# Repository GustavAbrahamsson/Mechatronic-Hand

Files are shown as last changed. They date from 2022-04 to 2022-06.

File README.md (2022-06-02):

# Mechatronic Hand

Mechatronic hand for bachelors thesis at Chalmers University of Technology.

### Members:

 - Gustav Abrahamsson 
 - Adam Anderson
 - Nicholas Granlund
 - Johannes Lundahl
 - Anna Molnö
 - Johan Wellander

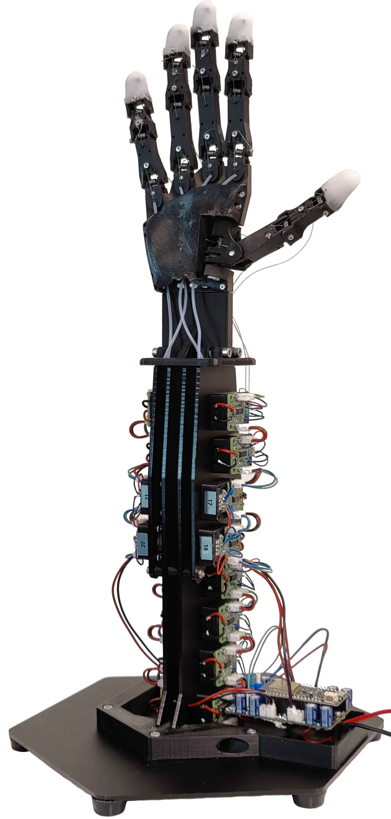
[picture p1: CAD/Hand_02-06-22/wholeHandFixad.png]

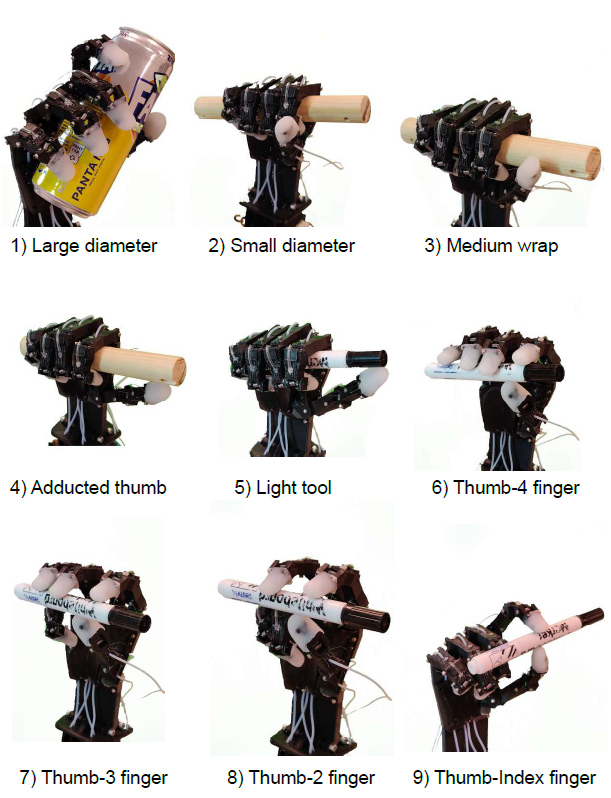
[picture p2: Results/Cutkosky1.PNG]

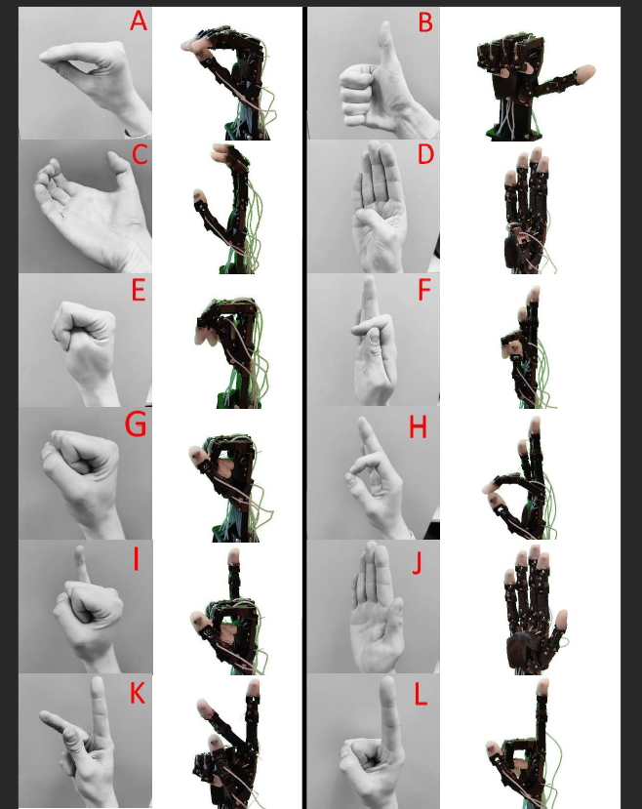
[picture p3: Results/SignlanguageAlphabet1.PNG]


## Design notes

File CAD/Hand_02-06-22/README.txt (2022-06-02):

Assembling this hand takes some time, but if you want to make it move it's going to take an eternity.
Soldering together 16 PCBs, crimping all of the jumper wires, calibrating setpoints from the potentiometers,
attaching wires and tightnening them etc is very time intensive and very troublesome. Feel free to try,
but we would recommend sticking with assembling the hand itself and maybe the lower arm WITHOUT the motors,
electronics and cables.

For the joints: Mostly M2 screws but with 4 M3 screws near the knuckles as well as an M4 and an M6 in the
base of the thumb.

The torsion springs were made by hand.

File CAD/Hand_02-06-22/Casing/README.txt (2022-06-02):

Not used in the final design, only tested. Silicone fingertips are so much better, but the other parts made it look more similar to a real hand.

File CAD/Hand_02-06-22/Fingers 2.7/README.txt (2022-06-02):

The Distal phalanges are similar for all four fingers, but there is either a straight one or a "T"-shaped one (used for silicone molded fingertip).

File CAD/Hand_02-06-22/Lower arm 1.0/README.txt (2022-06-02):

STL files to 3D print:
4 x 7mmDistans
2 x 8.8mmDistans
1 x Connector
1 x 3DprintedBase

DXF files to lasercut/CNC:
Everything is 3 mm thick matte black acrylic
2 x mainPlate1.0
2 x sidePlate1.0
1 x bottomPlate1.0

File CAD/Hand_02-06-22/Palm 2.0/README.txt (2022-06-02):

Palm2.0 was SLS printed, and FrontPalm1.2 was printed in an FDM printer with TPU plastic (not crucial though).
Make sure that the channels in the palm don't get filled up with support material, and if you SLS print; the excess filament might be difficult to remove.

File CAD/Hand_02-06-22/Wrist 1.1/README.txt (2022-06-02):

Not included in the final design due to the DC-motors only having 43% of the advertised torque..
It's therefore not finalized and cannot be mounted to the lower arm, only to the hand.

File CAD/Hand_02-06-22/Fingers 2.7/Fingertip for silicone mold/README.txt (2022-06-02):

Use this fingertip if you are going to cast silicone fingertips with the included molds

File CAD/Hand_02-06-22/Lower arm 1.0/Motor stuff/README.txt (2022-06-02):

16 of these are needed if you want to build it with motors.

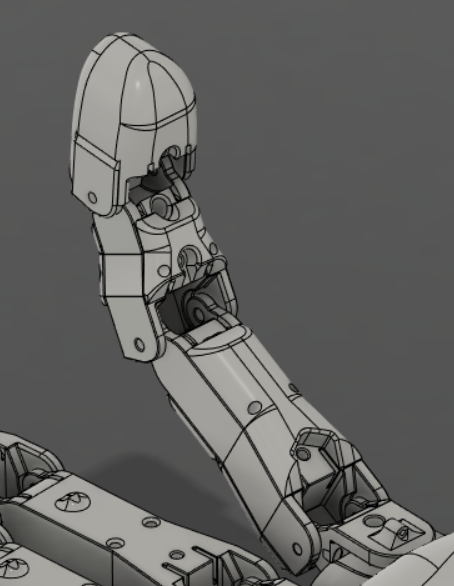
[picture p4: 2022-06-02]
CAD/Hand_02-06-22/Casing/CasingPicture.PNG

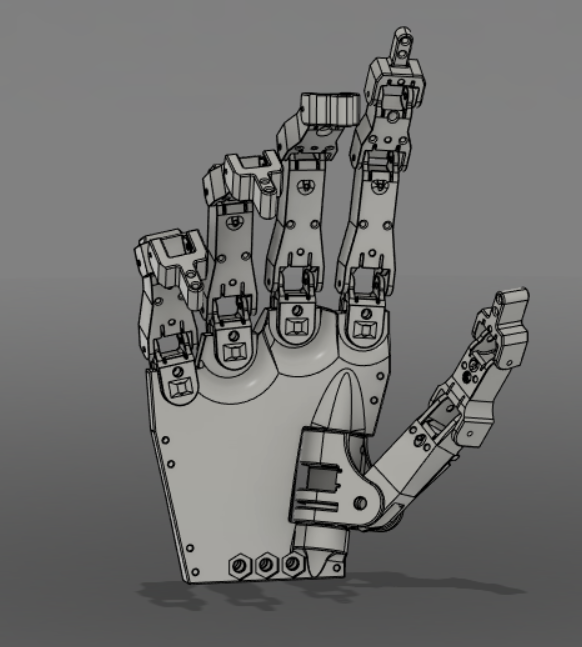
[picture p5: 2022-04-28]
CAD/Hand_02-06-22/Picture(withStraightFingertips).PNG

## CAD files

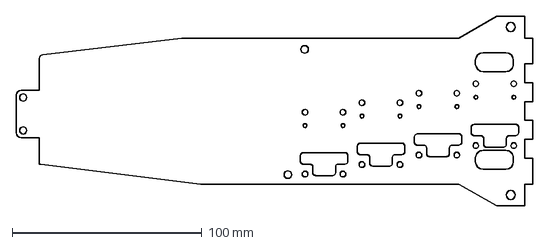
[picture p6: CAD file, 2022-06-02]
CAD/Hand_02-06-22/Lower arm 1.0/mainPlate1.0.dxf
272.1 x 99.9 mm

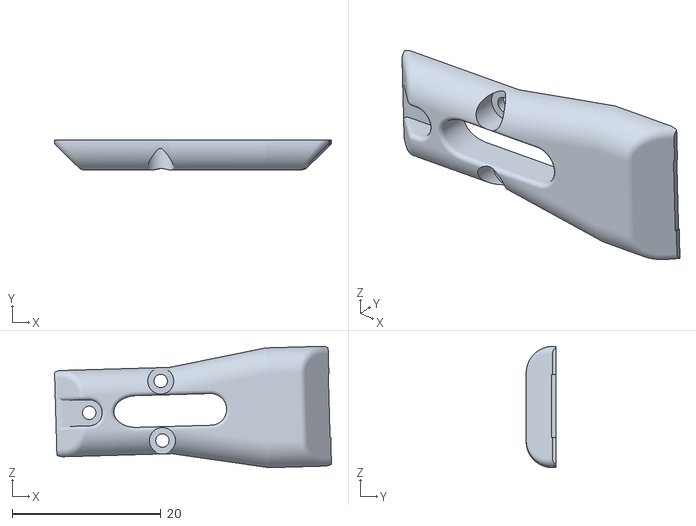
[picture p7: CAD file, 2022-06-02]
CAD/Hand_02-06-22/Casing/IndexProxBack.stl
37.2 x 4.02 x 16.3

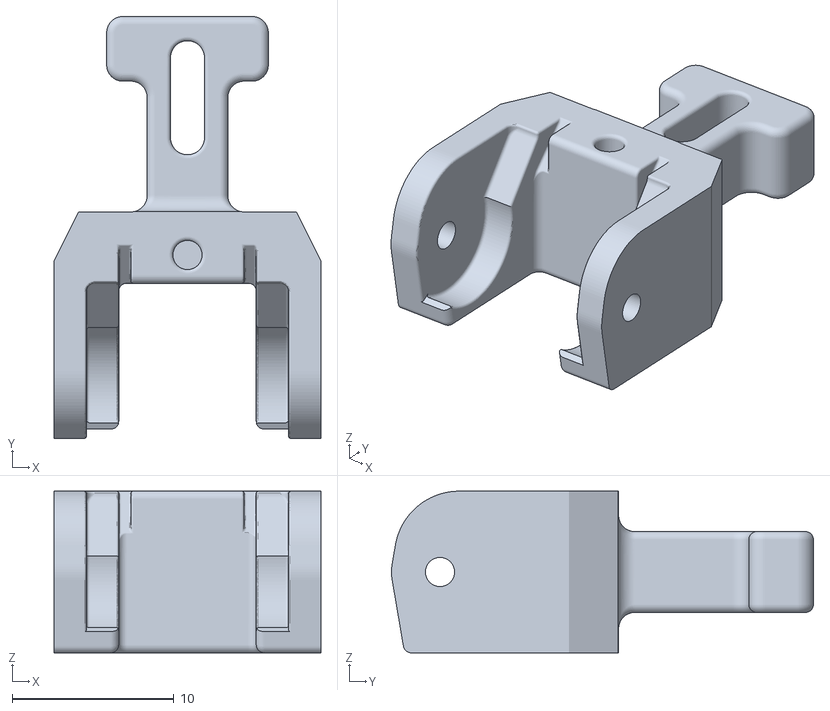
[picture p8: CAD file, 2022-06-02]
CAD/Hand_02-06-22/Fingers 2.7/Fingertip for silicone mold/Fingertip for silicone mold.stl
16.5 x 26.1 x 10.0

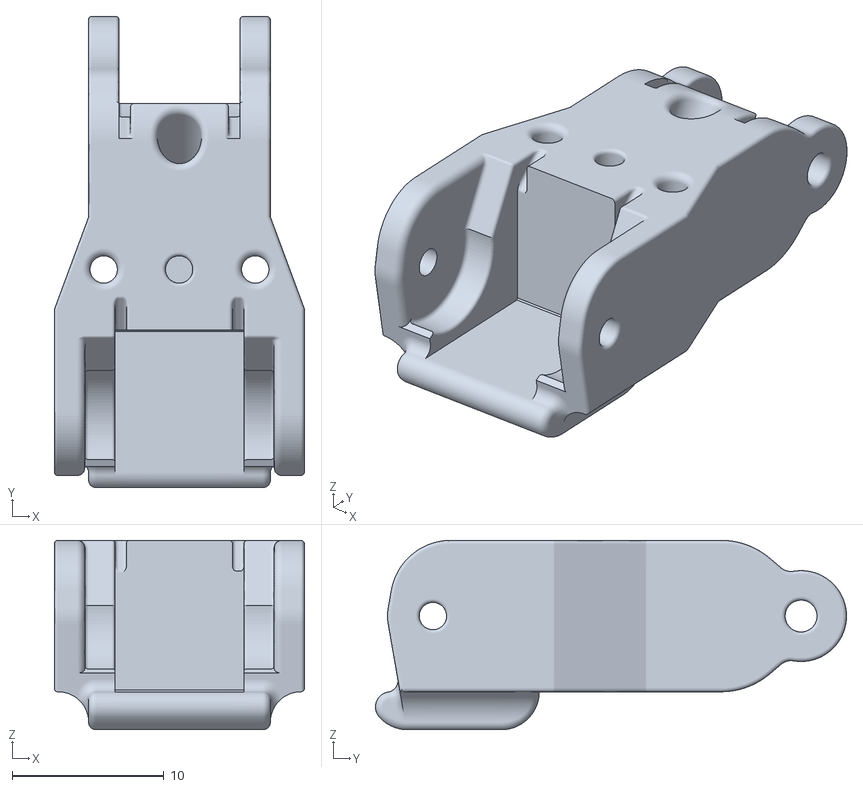
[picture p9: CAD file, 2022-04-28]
CAD/Hand_02-06-22/Fingers 2.7/Index/Intermediate phalanx.stl
16.5 x 31.1 x 12.5

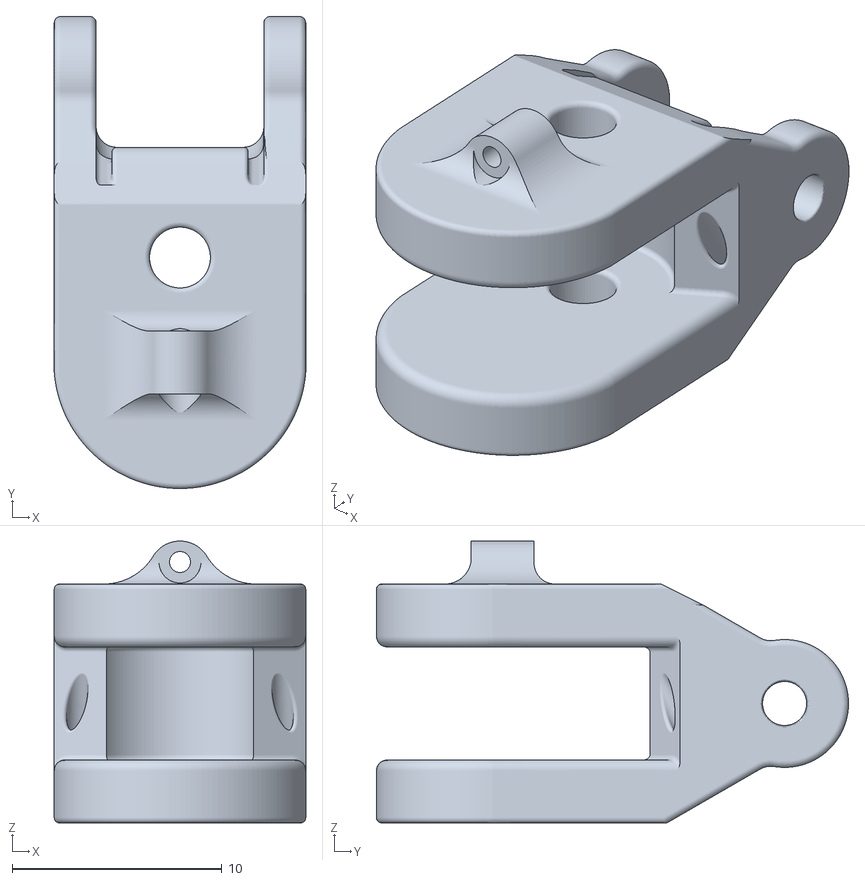
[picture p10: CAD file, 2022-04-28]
CAD/Hand_02-06-22/Fingers 2.7/Little/MCP_base.stl
12.0 x 22.5 x 13.4

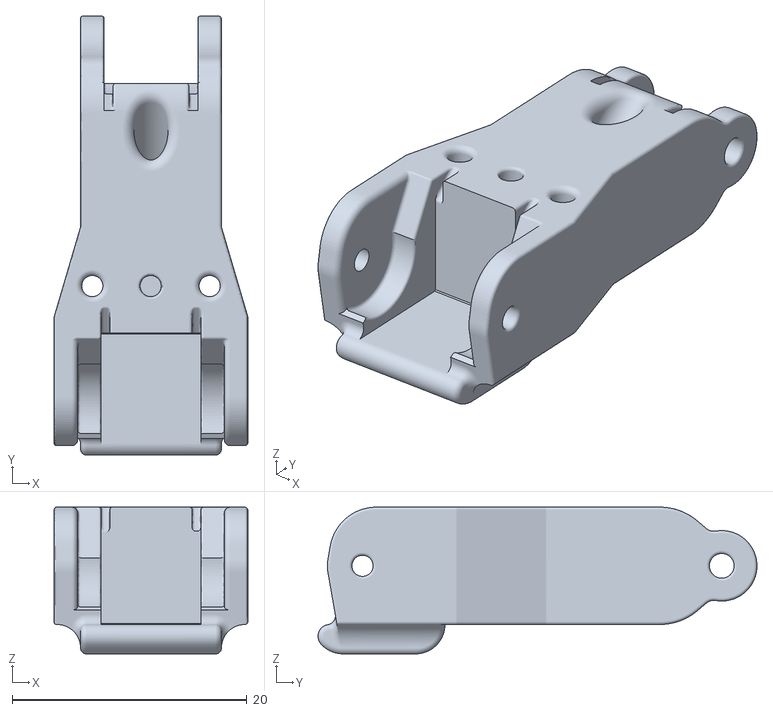
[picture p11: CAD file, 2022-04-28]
CAD/Hand_02-06-22/Fingers 2.7/Middle/Intermediate phalanx.stl
16.5 x 37.4 x 12.5

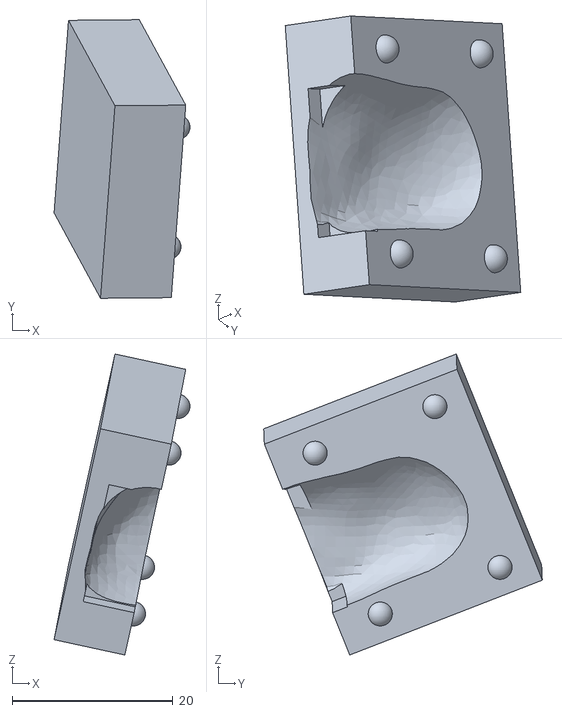
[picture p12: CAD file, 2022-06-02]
CAD/Hand_02-06-22/Fingers 2.7/Molds for finger tips/Finger mold/bottom.stl
16.9 x 34.6 x 37.4

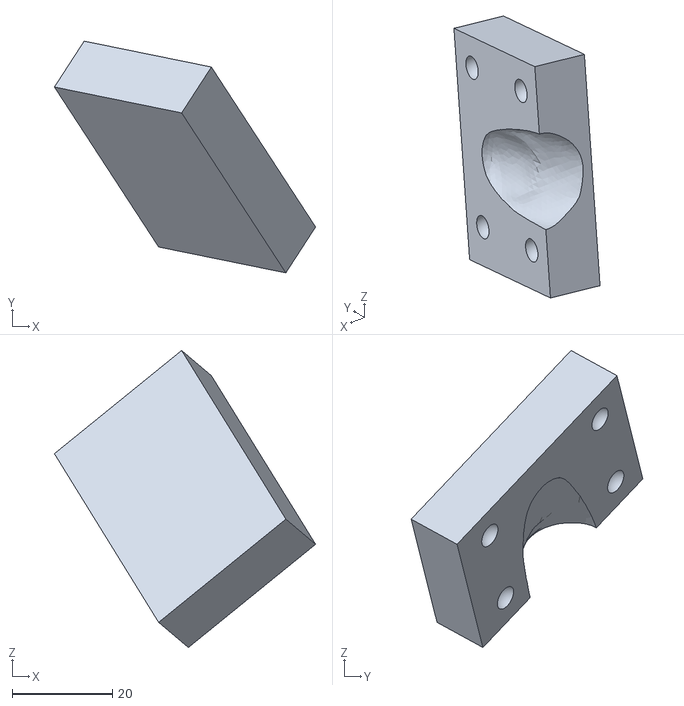
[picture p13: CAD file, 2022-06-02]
CAD/Hand_02-06-22/Fingers 2.7/Molds for finger tips/Thumb mold/Top.stl
52.1 x 46.2 x 59.2

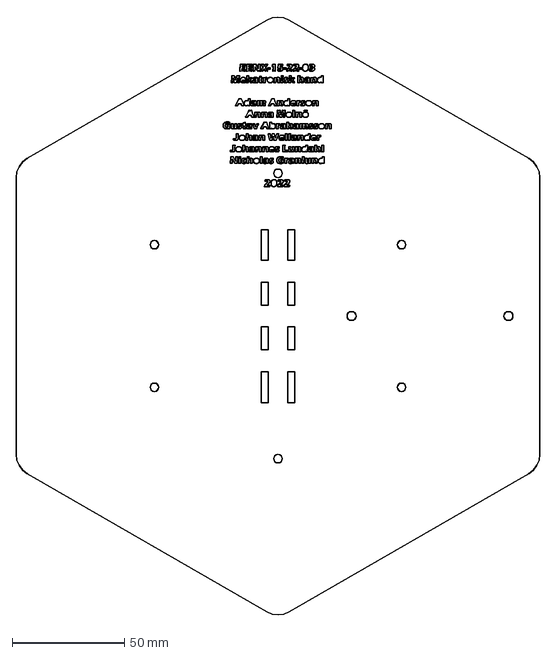
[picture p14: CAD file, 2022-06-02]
CAD/Hand_02-06-22/Lower arm 1.0/bottomPlate1.0.dxf
233.8 x 267.8 mm

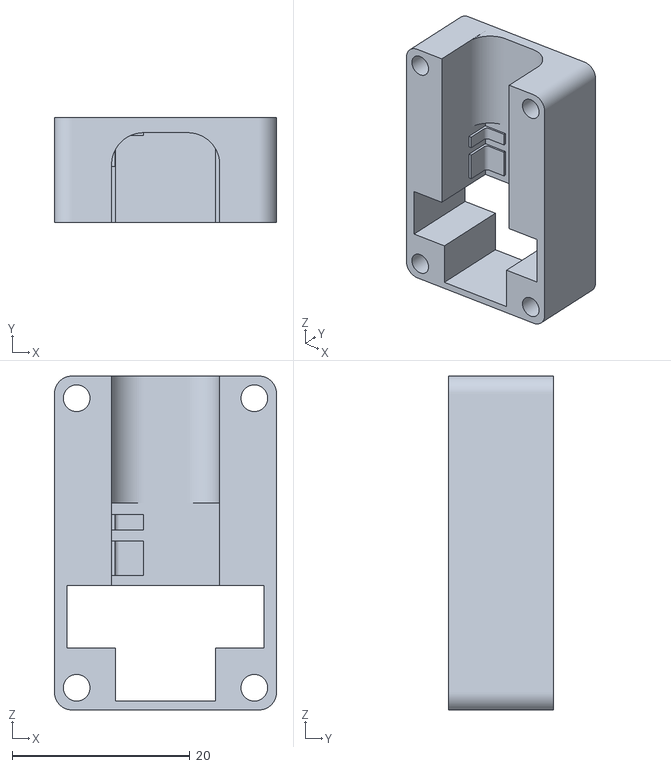
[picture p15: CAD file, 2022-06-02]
CAD/Hand_02-06-22/Lower arm 1.0/Motor stuff/Servoholder4.stl
25.0 x 11.8 x 37.6

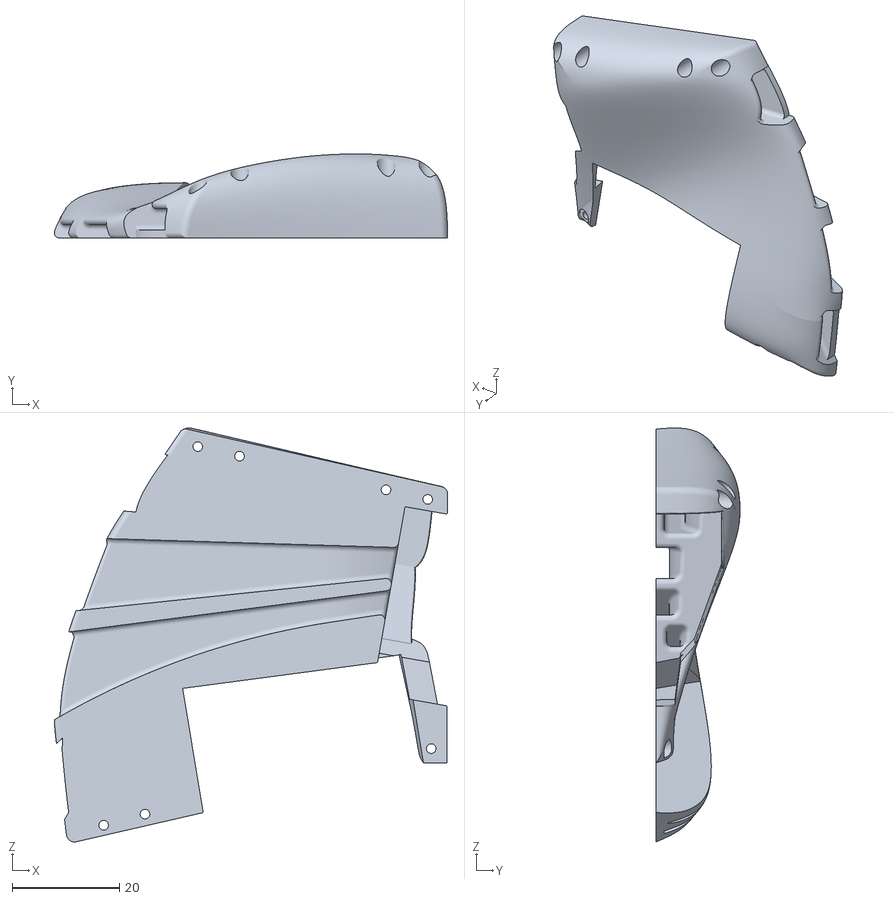
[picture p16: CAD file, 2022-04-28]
CAD/Hand_02-06-22/Palm 2.0/FrontPalm1.2.stl
73.5 x 15.7 x 77.4

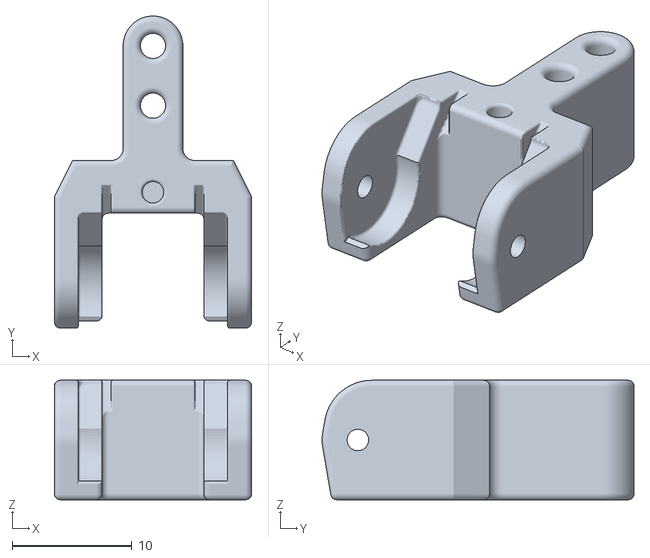
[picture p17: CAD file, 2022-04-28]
CAD/Hand_02-06-22/Thumb 1.5/distalthumbtest v1.stl
16.5 x 26.1 x 10.0

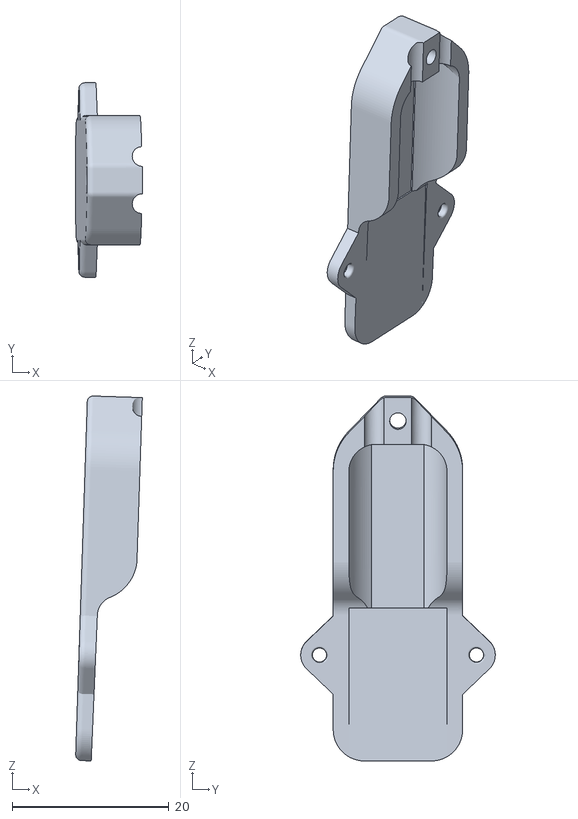
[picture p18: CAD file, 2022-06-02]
CAD/Hand_02-06-22/Wrist 1.1/MotorLid.stl
8.50 x 24.8 x 46.5

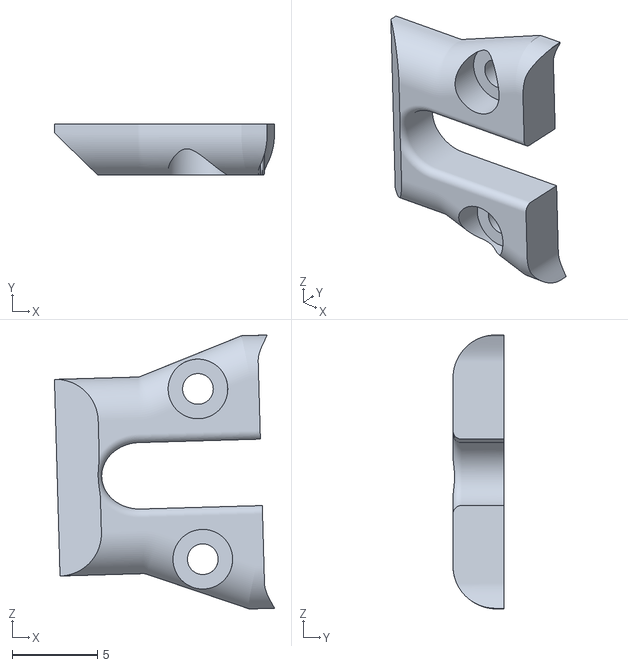
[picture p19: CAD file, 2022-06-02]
CAD/Hand_02-06-22/Casing/IndexInterBack.stl
12.9 x 3.01 x 16.1

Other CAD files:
CAD/Hand_02-06-22/Fingers 2.7/Index/Proximal phalanx.stl
CAD/Hand_02-06-22/Fingers 2.7/Little/Distal phalanx.stl
CAD/Hand_02-06-22/Fingers 2.7/Middle/Distal phalanx.stl
CAD/Hand_02-06-22/Casing/IndexInterFront.stl
CAD/Hand_02-06-22/Casing/IndexProxFront.stl
CAD/Hand_02-06-22/Casing/Short distal.stl
CAD/Hand_02-06-22/Casing/SoftDistal.stl
CAD/Hand_02-06-22/Fingers 2.7/Index/Distal phalanx.stl
CAD/Hand_02-06-22/Fingers 2.7/Little/Intermediate phalanx.stl
CAD/Hand_02-06-22/Fingers 2.7/Little/Proximal phalanx.stl
CAD/Hand_02-06-22/Fingers 2.7/Middle/MCP_base.stl
CAD/Hand_02-06-22/Fingers 2.7/Middle/Proximal phalanx.stl
CAD/Hand_02-06-22/Fingers 2.7/Molds for finger tips/Finger mold/top.stl
CAD/Hand_02-06-22/Fingers 2.7/Molds for finger tips/Thumb mold/Bottom.stl
CAD/Hand_02-06-22/Fingers 2.7/Ring/Distal phalanx.stl
CAD/Hand_02-06-22/Fingers 2.7/Ring/Intermediate phalanx.stl
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

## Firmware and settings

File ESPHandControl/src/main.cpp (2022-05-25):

#include <Arduino.h>
#include <WiFi.h>
#include <esp_now.h>
#include "MotorControl.h"
#include "Wire.h"
#include "angles.h"
#include "Math.h"

#define POT_IN 15
#define BTN 4

int letter = 0;
bool pressed = false;

uint32_t currentTime = 0;
uint32_t lastTime = 0;

uint32_t phaseShift = 3000;
float waveTime = 500.0;

uint8_t indexAngle  = 0;
uint8_t middleAngle = 0;
uint8_t ringAngle   = 0;
uint8_t littleAngle = 0;

uint8_t sequenceIndex = 0;

uint8_t CMCangle = 0;

int mode = 1;

enum joint{
  IP_TMB,
  MCP_TMB,
  CMC_TMB,
  ABD_TMB,
  MCP_1,
  PIP_1,
  ABD_1,
  MCP_2,
  PIP_2,
  ABD_2,
  MCP_3,
  PIP_3,
  ABD_3,
  MCP_4,
  PIP_4,
  ABD_4,
};

//List of 16 motor objects
MotorControl motors[16] = {
  MotorControl(11, 280, 50, 0, 90), // Thumb IP
  MotorControl(10, 440, 125, 0, 90), // Thumb MCP
  MotorControl(9, 445, 120, 0, 90), // Thumb rotation
  MotorControl(8, 448, 240, 0, 45), // Thumb abduction

  MotorControl(16, 260, 530, 0, 90), //MCP 1
  MotorControl(12, 130, 390, 0, 90), // PIP 1
  MotorControl(18, 540, 615, -15, 15), // ABD 1

  MotorControl(17, 240, 540, 0, 90 ), //MCP 2
  MotorControl(13, 330, 580, 0, 90), // PIP 2
  MotorControl(19, 530, 620, -15, 15), // ABD 2

  MotorControl(20, 710, 400, 0, 90), //MCP 3
  MotorControl(14, 275, 500, 0, 90), // PIP 3
  MotorControl(22, 520, 440, -15, 15), // ABD 3

  MotorControl(21, 710, 450, 0, 90), //MCP 4
  MotorControl(15, 270, 490, 0, 90), // PIP 4
  MotorControl(23, 670, 570, -15, 15), // ABD 4
};


//uint8_t broadcastAdress[] = {0x94,0xB9,0x7E,0xE4,0x84,0x34}; //MAC-adress till den svarta
//uint8_t broadcastAdress[] = {0x7C,0x9E,0xBD,0x60,0xD1,0x8C}; //MAC till den med kondensatorn
//uint8_t broadcastAdress[] = {0X7C,0X9E,0XBD,0X61,0X58,0XF4}; //MAC till den med vit tejp
uint8_t broadcastAdress[] = {0x94,0xB9,0x7E,0xE5,0x31,0xD8}; //MAC till Hand lolin

typedef struct struct_message{
  int sendID;
  float thumbIP;
  float thumbMCP;
  float finger1PIP;
  float finger1MCP;
  float finger2PIP;
  float finger2MCP;
  float finger3PIP;
  float finger3MCP;
  float finger4PIP;
  float finger4MCP;
  float thumbOpp;
  float finger1Pot;
  float finger2Po;
  float finger3Po;
  float finger4Po;
  float pot1;
  float pot2;
  float pot3;
  float pot4;
  float opposition;
 }struct_message;


struct_message msg_to_send;
struct_message recv_data;
float joint_positions[8];

// // Callback when data is sent, triggered when something is sent
void OnDataSent(const uint8_t *mac_addr, esp_now_send_status_t status) {
    Serial.print("\r\nLast Packet Send Status:\t");
    Serial.println(status == ESP_NOW_SEND_SUCCESS ? "Delivery Success" : "Delivery Fail");
}

// // Callback when data is received, triggered when something is recieved
void OnDataRecv(const uint8_t * mac, const uint8_t *incomingData, int len) {
  memcpy(&recv_data, incomingData, sizeof(recv_data));
  memcpy(&joint_positions, incomingData + 12, sizeof(joint_positions));

  Serial.print("Bytes received: ");
  Serial.println(len);
}


void getMACAdress(){
  WiFi.mode(WIFI_MODE_STA);
  Serial.println(WiFi.macAddress());
}

void init_wifi (){
  WiFi.mode(WIFI_STA);
  if (esp_now_init() != ESP_OK) {
    Serial.println("Error initializing ESP-NOW");
    return;
  }
 
  esp_now_register_send_cb(OnDataSent);
 
  esp_now_peer_info_t peerInfo;
  memcpy(peerInfo.peer_addr, broadcastAdress, 6);
  peerInfo.channel = 0;  
  peerInfo.encrypt = false;
 
  // if (esp_now_add_peer(&peerInfo) != ESP_OK){
  //   Serial.println("Failed to add peer");
  //   return;
  // }
  // Register for a callback function that will be called when data is received
  esp_now_register_recv_cb(OnDataRecv);
}

void send (){
  esp_now_send(0, (uint8_t *) &msg_to_send , sizeof(struct_message));
}

void setAllZero(){

  for(int i = 0; i < 16; i++){
    motors[i].angle_write(0);
  }
}


void setup() {
  // put your setup code here, to run once:
  Serial.begin(115200);
  Wire.begin();

  pinMode(POT_IN, INPUT);
  pinMode(BTN, INPUT_PULLDOWN);

  setAllZero();

  init_wifi();
  getMACAdress();

}

void loop() {

  currentTime = millis();
  char l = '0';  
  if(Serial.available()){
    l = Serial.read();
  }

  if (l == '1'){
    mode = 1;
    Serial.println("Mode 1: letters");
    delay(500);
  }else if (l == '2'){
    mode = 2;
    Serial.println("Mode 2: grasps");
    delay(500);
  }else if (l == '3'){
    mode = 3;
    Serial.println("Mode 3: demo");
    delay(500);
  }else if (l == '4'){
    mode = 4;
    Serial.println("Mode 4: glove");
    delay(500);
  }else if (mode == 1){
    // mode 1 = letters

    l = l-'a';

    if (l < 0 || l > 28){
      return;
    }

    // Write letter
    for (int i = 0; i < 16; i++)
    {
      motors[i].angle_write(letters[l][i]);
    }
  delay(500);

  }else if(mode == 2){
    // mode 2 = grasps

    l = l-'a';

    if (l < 0 || l > 16){
      return;
    }

    // Write grasp
    for (int i = 0; i < 16; i++)
    {
      motors[i].angle_write(grips[l][i]);
    }
  delay(500);
  }else if(mode == 3){
    // mode 3 = demo
    currentTime = currentTime % 45000;

    if(currentTime < 10000){
      indexAngle = 45 + 45*sin(currentTime/waveTime);
      motors[MCP_1].angle_write(indexAngle);
      motors[PIP_1].angle_write(indexAngle);

      middleAngle = 45 + 45*sin((currentTime + 2 * phaseShift)/waveTime);
      motors[MCP_2].angle_write(middleAngle);
      motors[PIP_2].angle_write(middleAngle);
      
      ringAngle = 45 + 45*sin((currentTime + 3 * phaseShift)/waveTime);
      motors[MCP_3].angle_write(ringAngle);
      motors[PIP_3].angle_write(ringAngle);
      
      littleAngle = 45 + 45*sin((currentTime + 4 * phaseShift)/waveTime);
      motors[MCP_4].angle_write(littleAngle);
      motors[PIP_4].angle_write(littleAngle);

      CMCangle = 10 + 10*sin((currentTime-waveTime)/waveTime);
      motors[CMC_TMB].angle_write(CMCangle);
      motors[IP_TMB].angle_write(2*CMCangle);
      motors[MCP_TMB].angle_write(2*CMCangle);

    
    }else if(currentTime < 11000){
      setAllZero();

    }else if(currentTime < 20000){
      motors[MCP_1].angle_write(0);
      motors[PIP_1].angle_write(0);
      motors[MCP_2].angle_write(0);
      motors[PIP_2].angle_write(0);
      motors[MCP_3].angle_write(0);
      motors[PIP_3].angle_write(0);
      motors[MCP_4].angle_write(0);
      motors[PIP_4].angle_write(0);
      motors[MCP_TMB].angle_write(0);
      motors[IP_TMB].angle_write(0);
      motors[CMC_TMB].angle_write(0);
      motors[ABD_TMB].angle_write(0);


      if(currentTime % 4000 < 1000){
        motors[ABD_1].angle_write(-15);
        motors[ABD_2].angle_write(-15);
        motors[ABD_3].angle_write(-15);
        motors[ABD_4].angle_write(-15);
      }else if(currentTime % 4000 < 2000){
        motors[ABD_1].angle_write(15);
        motors[ABD_2].angle_write(-15);
        motors[ABD_3].angle_write(-15);
        motors[ABD_4].angle_write(15);
      }else if(currentTime % 4000 < 3000){
        motors[ABD_1].angle_write(-15);
        motors[ABD_2].angle_write(-15);
        motors[ABD_3].angle_write(-15);
        motors[ABD_4].angle_write(-15);
      }else{
        motors[ABD_1].angle_write(10);
        motors[ABD_2].angle_write(15);
        motors[ABD_3].angle_write(15);
        motors[ABD_4].angle_write(0);
      }
    }else if(currentTime < 21000){
      setAllZero();
    }else if(currentTime < 35000){
      motors[ABD_1].angle_write(10);
      motors[ABD_4].angle_write(10);
      if(currentTime - lastTime > 750){
        lastTime = currentTime;
        sequenceIndex++;
        sequenceIndex %= 15;
        motors[sequenceIndex].angle_write(0);
        if(!((sequenceIndex + 1) % 3 == 0) || sequenceIndex == 2 ){
          motors[sequenceIndex + 1].angle_write(motors[sequenceIndex + 1].maxAngle);
        }
      }
    }else if(currentTime < 36000){
      setAllZero();
    }else{
      for(int i = 0; i < 16; i++){
        motors[i].angle_write(yeah[i]);
      }
    }
    delay(50);
  }else if(mode==4){

    motors[IP_TMB].angle_write(recv_data.thumbIP);
    motors[MCP_TMB].angle_write(recv_data.thumbIP);
    motors[CMC_TMB].angle_write(recv_data.thumbMCP);
    motors[PIP_1].angle_write(recv_data.finger1PIP);
    motors[MCP_1].angle_write(recv_data.finger1MCP);
    motors[PIP_2].angle_write(recv_data.finger2PIP);
    motors[MCP_2].angle_write(recv_data.finger2MCP);
    motors[PIP_3].angle_write(recv_data.finger3PIP);
    motors[MCP_3].angle_write(recv_data.finger3MCP);
    motors[PIP_4].angle_write(recv_data.finger4PIP);
    motors[MCP_4].angle_write(recv_data.finger4MCP);
  /*
    motors[ABD_1].angle_write(recv_data.finger1Pot);
    motors[ABD_2].angle_write(recv_data.finger2Po);
    motors[ABD_3].angle_write(recv_data.finger3Po);
    motors[ABD_4].angle_write(recv_data.finger4Po);
    */
    motors[ABD_1].angle_write(recv_data.finger1Pot);
    motors[ABD_2].angle_write(0);
    motors[ABD_3].angle_write(0);
    motors[ABD_4].angle_write(0);
  }
}

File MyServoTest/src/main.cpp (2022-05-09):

#include <Arduino.h>
#include <Wire.h>
#include "pidlib.h"
#include "potlib.h"

// Comment the following line for ATtiny
//#define NANO

// Nano Pins
#ifdef NANO
  #define MOTOR1 5
  #define MOTOR2 6
  #define LED 13 
  #define POT1 A0
  #define SPEEDPIN 7
#endif

// ATtiny pins
#ifndef NANO
  #define MOTOR1 PIN_PA4
  #define MOTOR2 PIN_PA5
  #define LED PIN_PA2 
  #define POT1 PIN_PA7
  #define POT2 PIN_PA1
  #define CURRENTPIN PIN_PA6
#endif

#define I2CAddress 23
#define DT 5

const float Kp=2, Ki=10, Kd=0.5;
const float FILTER = 0.2;

volatile int16_t setpoint;
int16_t output;

volatile int16_t minPosition = 0;
volatile int16_t maxPosition = 0xFFFF;

volatile uint8_t current;
volatile uint8_t maxCurrent = 255;

volatile uint8_t command;
volatile int16_t deg;

MyPID MyPIDD(Kp, Ki, Kd);
POTSwitch MyPOTSwitch(POT1, POT2, FILTER);

// I2C communication spec.

// Desc.        Command ID      length (bytes)      Read/Write
// I2C addr     0               1                   R
// Position*    1               1                   R
// Setpoint*    2               1                   R/W      
// Current      3               1                   R
// Max Current* 4               1                   R/W
// MinLimit*    5               2                   R/W
// MaxLimit*    6               2                   R/W
// RawPosition  7               2                   R
// RawSetpoint  8               2                   R/W  
// AutoLimits*  9               0                   W
// PID Out     10               2                   R

// *Not yet implemented

// Request to read data
void requestEvent(){
  switch (command)
  {
  case 0: //I2C address
    Wire.write(I2CAddress);
    break;

  case 1: //Position
    Wire.write(map(deg, minPosition, maxPosition, 0, 255));
    break;

  case 2: //Setpoint
    Wire.write(map(setpoint, minPosition, maxPosition, 0, 255));
    break;

  case 3: // Current
    Wire.write(current);
    break;

  case 4: // Max Current
    Wire.write(maxCurrent);
    break;

  case 5: // Min limit
    Wire.write((uint8_t) minPosition & 0xFF);
    Wire.write((uint8_t) (minPosition<<8) & 0xFF);
    break;

  case 6: // Max limit
    Wire.write((uint8_t) maxPosition & 0xFF);
    Wire.write((uint8_t) (maxPosition<<8) & 0xFF);
    break;

  case 7: // Raw position
    Wire.write((uint8_t) deg);
    Wire.write((uint8_t) (deg>>8));
    break;

  case 8: // Raw setpoint
    Wire.write((uint8_t) setpoint);
    Wire.write((uint8_t) (setpoint>>8));
    break;  

  case 10: // PID output
    Wire.write((uint8_t) output);
    Wire.write((uint8_t) (output>>8));
    break;  


  default:
    break;
  }
}

// Write from controller
void recieveEvent(int numbytes){
  command = Wire.read();

  uint8_t buff[3];
  int i = 0;
  while(Wire.available()){
    buff[i] = Wire.read();
    i++;
  }

  switch (command)
  {
  case 2: // new setpoint
    setpoint = buff[0];
    setpoint += buff[1]<<8;
    break;

  case 4: // Max current
    current = buff[0];
    break;

  case 5: // Min Limit
    minPosition = buff[0];
    minPosition += buff[1]<<8;
    break;

  case 6: // Min Limit
    maxPosition = buff[0];
    maxPosition += buff[1]<<8;
    break;

  case 8: // raw setpoint
    setpoint = buff[0];
    setpoint |= buff[1]<<8;
    break;
 
  default:
    break;
  }

}


void setup() {
  // put your setup code here, to run once:
  #ifdef NANO
    Serial.begin(115200);
  #endif

  // Use higher PWM frequency to remove noise
  #ifndef NANO
    TCA0.SPLIT.CTRLA = TCA_SINGLE_CLKSEL_DIV2_gc | TCA_SINGLE_ENABLE_bm;
  #endif

  pinMode(LED, OUTPUT);
  digitalWrite(LED, HIGH);
  pinMode(POT1, INPUT_PULLUP);
  pinMode(POT2, INPUT_PULLUP);
  pinMode(CURRENTPIN, INPUT);
  pinMode(MOTOR1, OUTPUT);
  pinMode(MOTOR2, OUTPUT);
  Wire.begin(I2CAddress);
  Wire.onRequest(requestEvent);
  Wire.onReceive(recieveEvent);
  delay(100);
  digitalWrite(LED, LOW);

  MyPOTSwitch.reset();
  setpoint = MyPOTSwitch.decidePot();
};

void loop() {

  // Decide what potentiometer to send to PID
  deg = MyPOTSwitch.decidePot();

  // Measure current from current sensor
  current = analogRead(CURRENTPIN);
  
  // Use PID to determine output
  int set = setpoint;

  if (set > 975){
    set = 975;
  }else if (set < 50){
    set = 50;
  }

  output = MyPIDD.nextStep(set, deg);

  #ifdef NANO
    Serial.print("DEG:\t");
    Serial.print(deg);
    Serial.print("\tOUTPUT:\t");
    Serial.println(output);
  #endif

  if (output < 0){
    analogWrite(MOTOR2, 0);

    #ifndef NANO
      analogWrite(MOTOR1, -output);
    #endif

    #ifdef NANO
      analogWrite(MOTOR1, 255);
      analogWrite(SPEEDPIN, -output);
    #endif
  }
  else{
    analogWrite(MOTOR1, 0);

    #ifndef NANO
      analogWrite(MOTOR2, output);
    #endif

    #ifdef NANO
      analogWrite(MOTOR2, 255);
      analogWrite(SPEEDPIN, output);
    #endif
  }

  delay(DT);

}

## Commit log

2022-03-31 Handle i2c writes
2022-03-31 Test i2C write
2022-04-07 Macro for switching boards
2022-04-13 I2C communication in motor driver
2022-04-13 I2C comms for ESP32
2022-04-18 Added current read
2022-04-18 Add timing to PID library
2022-04-27 Test PID
2022-04-27 Proper filter of pots
2022-04-28 Add CAD
    [CMCpart.stl, Distal phalanx.stl, FrontPalm1.2.stl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]
2022-05-06 All motors rough values
2022-06-02 Add CAD and info
    [3DprintedBase.stl, 7mmDistans.stl, 8.8mmDistans.stl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]
